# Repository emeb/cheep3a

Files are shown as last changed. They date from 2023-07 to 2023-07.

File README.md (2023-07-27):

# cheep3a
An inexpensive Eurorack audio generator

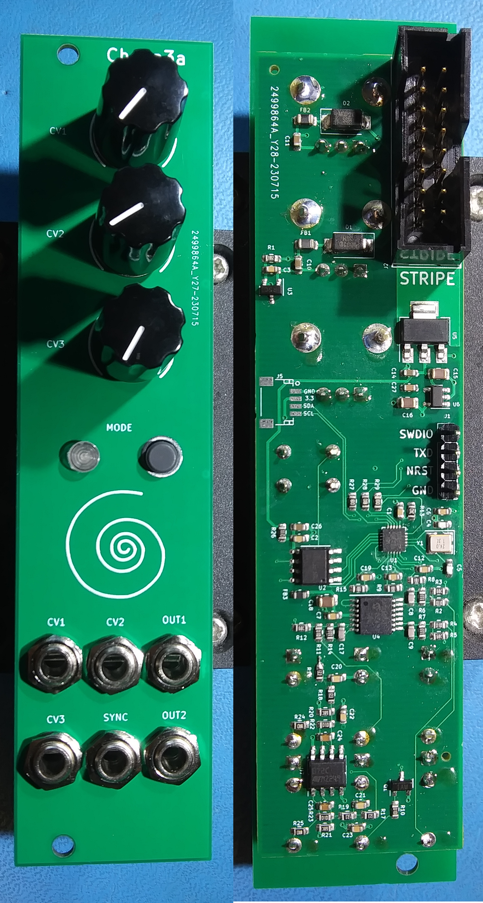
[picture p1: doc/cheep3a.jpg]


## Abstract
This project is an extension of previous "Cheep" Eurorack modules which have been
built as demonstrations for simple, low-cost audio generators using low-end MCUs
and DACs. Cheep3a targets the recently introduced CH32V003 RISC-V based MCU from
WCH Inc. in order to explore the feasibility of audio generation with a sub-$1.00
microcontroller.

## Features
Cheep3a provides the following features:
* Three Control Voltage inputs with 10-bit 10Vpp instantaneous range over a +/-11V
adjustable range using offset potentiometers.
* One digital input for trigger/gate/sync.
* Two +/-5V audio outputs with 16-bit resolution and 48kHz sample rate.
* One mode select button
* One RGB LED for mode indication.
* 4-pin programming interface, including 1-line WCH standard SWDIO, UART TX and
Reset signal.
* JST SH-4 connector with optional I2C signals compatible with StemmaQT/Qwiic
connections for off-board expansion.
* Standard 16-pin Eurorack power with shrouded header and +/-12V supply.

## Firmware
Firmware included in this project supports seven operating modes with various
audio signal outputs in each mode:
1. [Red] Two independent sine oscillators with amplitude control - 10Hz - 10kHz
frequency range.
2. [Green] Same as 1 but with 0.3Hz - 300Hz frequency range.
3. [Yellow] One sine oscillator with two outputs, phase offset and amplitude
control - 10Hz - 10kHz frequency range.
4. [Blue] Pulse wave oscillator with two outputs and independent PWM
controls - 10Hz - 10kHz frequency range.
5. [Magenta] 2-operator FM with index and ratio controls. Mod and Carrier outputs.
6. [Cyan] Two independent clocked noise outputs.
7. [White] White and Pink noise outputs.

Mode selection is stored in the MCU's on-chip flash memory and will persist
across power cycles.

### Building Firmware
The Cheep3a firmware is based on [cnlohr's "ch32v003fun"](https://github.com/cnlohr/ch32v003fun)
project and expects that the github directory for that project is located in
an adjacent directory in order for the make-based build system to operate
correctly. A recent RISC-V GCC toolchain is also required and once you have
that installed (and in your search path) the following steps should work:

```
git clone git@github.com:emeb/cheep3a.git
git clone git@github.com:cnlohr/ch32v003fun.git
cd cheep3a/firmware
make
```

## Hardware
Version 0.1 of the hardware was fabbed and assembled at JLCPCB at modest cost and
all unsupported components (pots, jacks, connectors, LED and button) were added
by hand. Aside from a few minor layout errors which were easily corrected, the
system performed as expected.

### Building Hardware
The hardware can be recreated with the following steps:
1. Open the PCB project in Kicad and generate Gerber and Drill files. Zip them
up together and submit to the PCB fab of choice.
2. Generate component placement information and format as required by your
PCB assembly house.
3. The JLCPCB formatted BOM is included in the hardware directory and maps to
components that were available at the time I designed this board. If you don't
use JLCPCB the BOM may need to be reformatted and substitutions of parts will
likely be necessary.
4. Follow the submission process for your PCB house, including correction of
placement and approval of components.

## Lessons Learned
The CH32V003 MCU performs well for simple audio generation tasks but falls
somewhat short for more complex DSP. Hardware support for good digital audio is
impaired by the overall low CPU clock speed and limited memory capcity, as well
as the need to "work around" the lack of true I2S serial audio interfacing. The
biggest shortcoming however is the subset RV32E RISC-V CPU which doesn't provide
hardware multiply and thus significantly increases the cost of even simple DSP
operations needed for good-quality audio generation.

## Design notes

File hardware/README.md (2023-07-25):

# Hardware
This directory contains the KiCad project files for the Cheep3a hardware design.

# Version
This is Version 0.2

* Version 0.1 of the design was fabbed and assembled by JLCPCB and several minor
issues were discovered. These issues were corrected and the system performed as
designed.
* Version 0.2 corrects the errors found in V0.1 but has not been built or tested.

# Panel Design
The directory `cheep3a_panel` contains a front panel design for standard 3U
Eurorack mounting.

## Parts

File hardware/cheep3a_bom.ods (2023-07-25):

Source: | /home/ericb/Engineering/KBADC/kicad/cheep3a/cheep3a.kicad_sch
Date: | Fri 14 Jul 2023 01:16:01 PM MST
Tool: | Eeschema 6.0.11-3.fc36
Generator: | /usr/share/kicad/plugins/bom_csv_grouped_by_value.py
Component Count: | 84
Individual Components:
Item | Qty | Reference(s) | Value | Footprint | JLC
 |  | C1 | 0.1uf | Capacitor_SMD:C_0603_1608Metric | https://jlcpcb.com/partdetail/Yageo-CC0603KRX7R9BB104/C14663
 |  | C2 | 0.1uf | Capacitor_SMD:C_0603_1608Metric | https://jlcpcb.com/partdetail/Yageo-CC0603KRX7R9BB104/C14663
 |  | C3 | 0.1uf | Capacitor_SMD:C_0603_1608Metric | https://jlcpcb.com/partdetail/Yageo-CC0603KRX7R9BB104/C14663
 |  | C4 | 27pf | Capacitor_SMD:C_0603_1608Metric | https://jlcpcb.com/partdetail/Yageo-CC0603JRNPO9BN270/C107045
 |  | C5 | 27pf | Capacitor_SMD:C_0603_1608Metric | https://jlcpcb.com/partdetail/Yageo-CC0603JRNPO9BN270/C107045
 |  | C6 | 0.1uf | Capacitor_SMD:C_0603_1608Metric | https://jlcpcb.com/partdetail/Yageo-CC0603KRX7R9BB104/C14663
 |  | C7 | 0.1uf | Capacitor_SMD:C_0603_1608Metric | https://jlcpcb.com/partdetail/Yageo-CC0603KRX7R9BB104/C14663
 |  | C8 | 330pf | Capacitor_SMD:C_0603_1608Metric | https://jlcpcb.com/partdetail/2016-CL10C331JB8NNNC/C1664
 |  | C9 | 330pf | Capacitor_SMD:C_0603_1608Metric | https://jlcpcb.com/partdetail/2016-CL10C331JB8NNNC/C1664
 |  | C10 | 1uf | Capacitor_SMD:C_0603_1608Metric | https://jlcpcb.com/partdetail/16531-CL10A105KB8NNNC/C15849
 |  | C11 | 1uf | Capacitor_SMD:C_0603_1608Metric | https://jlcpcb.com/partdetail/16531-CL10A105KB8NNNC/C15849
 |  | C12 | 0.1uf | Capacitor_SMD:C_0603_1608Metric | https://jlcpcb.com/partdetail/Yageo-CC0603KRX7R9BB104/C14663
 |  | C13 | 0.1uf | Capacitor_SMD:C_0603_1608Metric | https://jlcpcb.com/partdetail/Yageo-CC0603KRX7R9BB104/C14663
 |  | C14 | 1uf | Capacitor_SMD:C_0603_1608Metric | https://jlcpcb.com/partdetail/16531-CL10A105KB8NNNC/C15849
 |  | C15 | 10uf | Capacitor_SMD:C_0805_2012Metric | https://jlcpcb.com/partdetail/439567-GRM21BR61H106KE43L/C440198
 |  | C16 | 10uf | Capacitor_SMD:C_0805_2012Metric | https://jlcpcb.com/partdetail/439567-GRM21BR61H106KE43L/C440198
 |  | C17 | 330pf | Capacitor_SMD:C_0603_1608Metric | https://jlcpcb.com/partdetail/2016-CL10C331JB8NNNC/C1664
 |  | C18 | 10uf | Capacitor_SMD:C_0805_2012Metric | https://jlcpcb.com/partdetail/439567-GRM21BR61H106KE43L/C440198
 |  | C19 | 0.1uf | Capacitor_SMD:C_0603_1608Metric | https://jlcpcb.com/partdetail/Yageo-CC0603KRX7R9BB104/C14663
 |  | C20 | 3.3nf | Capacitor_SMD:C_0603_1608Metric | https://jlcpcb.com/partdetail/1965-CL10B332KB8NNNC/C1613
 |  | C21 | 3.3nf | Capacitor_SMD:C_0603_1608Metric | https://jlcpcb.com/partdetail/1965-CL10B332KB8NNNC/C1613
 |  | C22 | 0.1uf | Capacitor_SMD:C_0603_1608Metric | https://jlcpcb.com/partdetail/Yageo-CC0603KRX7R9BB104/C14663
 |  | C23 | 0.1uf | Capacitor_SMD:C_0603_1608Metric | https://jlcpcb.com/partdetail/Yageo-CC0603KRX7R9BB104/C14663
 |  | C24 | 150pf | Capacitor_SMD:C_0603_1608Metric | https://jlcpcb.com/partdetail/1946-0603B151K500NT/C1594
 |  | C25 | 150pf | Capacitor_SMD:C_0603_1608Metric | https://jlcpcb.com/partdetail/1946-0603B151K500NT/C1594
 |  | C26 | 1uf | Capacitor_SMD:C_0603_1608Metric | https://jlcpcb.com/partdetail/16531-CL10A105KB8NNNC/C15849
 |  | C27 | 10nf | Capacitor_SMD:C_0603_1608Metric | https://jlcpcb.com/partdetail/58143-0603B103K500NT/C57112
 |  | D1 | SS14 | Diode_SMD:D_SMA | https://jlcpcb.com/partdetail/Mdd-SS14/C2480
 |  | D2 | SS14 | Diode_SMD:D_SMA | https://jlcpcb.com/partdetail/Mdd-SS14/C2480
 |  | D3 | CLX6F-FKC | LED_SMD:LED_RGB_PLCC-6
 |  | FB1 | GZ2012D601TF | Inductor_SMD:L_0805_2012Metric | https://jlcpcb.com/partdetail/Sunlord-GZ2012D601TF/C1017
 |  | FB2 | GZ2012D601TF | Inductor_SMD:L_0805_2012Metric | https://jlcpcb.com/partdetail/Sunlord-GZ2012D601TF/C1017
 |  | FB3 | GZ1608D222TF | Inductor_SMD:L_0603_1608Metric | https://jlcpcb.com/partdetail/Sunlord-GZ1608D222TF/C96697
 |  | J1 | PROGRAM | Connector_PinHeader_2.54mm:PinHeader_1x04_P2.54mm_Vertical
 |  | J2 | Conn_02x08_Odd_Even | emeb_library:con16_2X8_S4_TEC
 |  | J3 | AudioJack2_SwitchT | emeb_library:Jack_3.5mm_QingPu_WQP-PJ398SM_Vertical_CircularHoles
 |  | J4 | AudioJack2_SwitchT | emeb_library:Jack_3.5mm_QingPu_WQP-PJ398SM_Vertical_CircularHoles
 |  | J5 | JST SH-4 (Qwiic) | emeb_library:JST_SH_SM04B-SRSS-TB_04x1.00mm_Angled
 |  | J6 | AudioJack2_SwitchT | emeb_library:Jack_3.5mm_QingPu_WQP-PJ398SM_Vertical_CircularHoles
 |  | J7 | AudioJack2_SwitchT | emeb_library:Jack_3.5mm_QingPu_WQP-PJ398SM_Vertical_CircularHoles
 |  | J8 | AudioJack2_SwitchT | emeb_library:Jack_3.5mm_QingPu_WQP-PJ398SM_Vertical_CircularHoles
 |  | J9 | AudioJack2_SwitchT | emeb_library:Jack_3.5mm_QingPu_WQP-PJ398SM_Vertical_CircularHoles
 |  | Q1 | MMBT3904 | Package_TO_SOT_SMD:SOT-23 | https://jlcpcb.com/partdetail/Goodwork-MMBT3904/C909754
 |  | R1 | 1.5k | Resistor_SMD:R_0603_1608Metric | https://jlcpcb.com/partdetail/21904-0603WAF1001T5E/C21190
 |  | R2 | 100k | Resistor_SMD:R_0603_1608Metric | https://jlcpcb.com/partdetail/26546-0603WAF1003T5E/C25803
 |  | R3 | 49.9k | Resistor_SMD:R_0603_1608Metric | https://jlcpcb.com/partdetail/23911-0603WAF4992T5E/C23184
 |  | R4 | 100k | Resistor_SMD:R_0603_1608Metric | https://jlcpcb.com/partdetail/26546-0603WAF1003T5E/C25803
 |  | R5 | 49.9k | Resistor_SMD:R_0603_1608Metric | https://jlcpcb.com/partdetail/23911-0603WAF4992T5E/C23184
 |  | R6 | 33k | Resistor_SMD:R_0603_1608Metric | https://jlcpcb.com/partdetail/4623-0603WAF3302T5E/C4216
 |  | R7 | 33k | Resistor_SMD:R_0603_1608Metric | https://jlcpcb.com/partdetail/4623-0603WAF3302T5E/C4216
 |  | R8 | 180 | Resistor_SMD:R_0603_1608Metric | https://jlcpcb.com/partdetail/23555-0603WAF1800T5E/C22828
 |  | R9 | 180 | Resistor_SMD:R_0603_1608Metric | https://jlcpcb.com/partdetail/23555-0603WAF1800T5E/C22828
 |  | R10 | 100k | Resistor_SMD:R_0603_1608Metric | https://jlcpcb.com/partdetail/26546-0603WAF1003T5E/C25803
 |  | R11 | 100k | Resistor_SMD:R_0603_1608Metric | https://jlcpcb.com/partdetail/26546-0603WAF1003T5E/C25803
 |  | R12 | 49.9k | Resistor_SMD:R_0603_1608Metric | https://jlcpcb.com/partdetail/23911-0603WAF4992T5E/C23184
 |  | R13 | 10k | Resistor_SMD:R_0603_1608Metric | https://jlcpcb.com/partdetail/26547-0603WAF1002T5E/C25804
 |  | R14 | 33k | Resistor_SMD:R_0603_1608Metric | https://jlcpcb.com/partdetail/4623-0603WAF3302T5E/C4216
 |  | R15 | 180 | Resistor_SMD:R_0603_1608Metric | https://jlcpcb.com/partdetail/23555-0603WAF1800T5E/C22828
 |  | R16 | 12k | Resistor_SMD:R_0603_1608Metric | https://jlcpcb.com/partdetail/23517-0603WAF1202T5E/C22790
 |  | R17 | 12k | Resistor_SMD:R_0603_1608Metric | https://jlcpcb.com/partdetail/23517-0603WAF1202T5E/C22790
 |  | R18 | 12k | Resistor_SMD:R_0603_1608Metric | https://jlcpcb.com/partdetail/23517-0603WAF1202T5E/C22790
 |  | R19 | 12k | Resistor_SMD:R_0603_1608Metric | https://jlcpcb.com/partdetail/23517-0603WAF1202T5E/C22790
 |  | R20 | 49.9k | Resistor_SMD:R_0603_1608Metric | https://jlcpcb.com/partdetail/23911-0603WAF4992T5E/C23184
 |  | R21 | 49.9k | Resistor_SMD:R_0603_1608Metric | https://jlcpcb.com/partdetail/23911-0603WAF4992T5E/C23184
 |  | R22 | 100k | Resistor_SMD:R_0603_1608Metric | https://jlcpcb.com/partdetail/26546-0603WAF1003T5E/C25803
 |  | R23 | 100k | Resistor_SMD:R_0603_1608Metric | https://jlcpcb.com/partdetail/26546-0603WAF1003T5E/C25803
 |  | R24 | 100 | Resistor_SMD:R_0603_1608Metric | https://jlcpcb.com/partdetail/23502-0603WAF1000T5E/C22775
 |  | R25 | 100 | Resistor_SMD:R_0603_1608Metric | https://jlcpcb.com/partdetail/23502-0603WAF1000T5E/C22775
 |  | R26 | 10 | Resistor_SMD:R_0603_1608Metric | https://jlcpcb.com/partdetail/23586-0603WAF100JT5E/C22859
 |  | R27 | 1k | Resistor_SMD:R_0603_1608Metric | https://jlcpcb.com/partdetail/21904-0603WAF1001T5E/C21190
 |  | R28 | 1k | Resistor_SMD:R_0603_1608Metric | https://jlcpcb.com/partdetail/21904-0603WAF1001T5E/C21190
 |  | R29 | 1k | Resistor_SMD:R_0603_1608Metric | https://jlcpcb.com/partdetail/21904-0603WAF1001T5E/C21190
 |  | RV1 | 10k | emeb_library:Potentiometer_TT_P0915N
 |  | RV2 | 10k | emeb_library:Potentiometer_TT_P0915N
 |  | RV3 | 10k | emeb_library:Potentiometer_TT_P0915N
 |  | SW1 | SW_Push | Button_Switch_THT:SW_PUSH_6mm
 |  | U1 | CH32V003F4U6 | Package_DFN_QFN:QFN-20-1EP_3x3mm_P0.4mm_EP1.65x1.65mm_ThermalVias | https://jlcpcb.com/partdetail/wch_jiangsu_Qin_heng-CH32V003F4U6/C5299908
 |  | U2 | PT8211-S | Package_SO:SO-8_3.9x4.9mm_P1.27mm | https://jlcpcb.com/partdetail/ptc_princeton_tech-PT8211S/C92004
 |  | U3 | LM4040C50FTA | Package_TO_SOT_SMD:SOT-23 | https://jlcpcb.com/partdetail/DiodesIncorporated-LM4040C50FTA/C156291
 |  | U4 | MCP6004-I/ST | Package_SO:TSSOP-14_4.4x5mm_P0.65mm | https://jlcpcb.com/partdetail/MicrochipTech-MCP6004T_IST/C50282
 |  | U5 | ME6118A50B3G | Package_TO_SOT_SMD:SOT-223-3_TabPin2 | https://jlcpcb.com/partdetail/162404-ME6118A50B3G/C151064
 |  | U6 | BCT2028EUK33 | Package_TO_SOT_SMD:SOT-23-5 | https://jlcpcb.com/partdetail/Broadchip-BCT2028EUK33TR/C266766
 |  | U7 | TL072CDT | Package_SO:SOIC-8_3.9x4.9mm_P1.27mm | https://jlcpcb.com/partdetail/Stmicroelectronics-TL072CDT/C6961
 |  | Y1 | SX32Y024000BK1T | Crystal:Crystal_SMD_3225-4Pin_3.2x2.5mm | https://jlcpcb.com/partdetail/Tkd-SX32Y024000BK1T/C271630
Collated Components:
Item | Qty | Reference(s) | Value | Footprint | JLC | checked?
1 | 10 | C1, C2, C3, C6, C7, C12, C13, C19, C22, C23 | 0.1uf | Capacitor_SMD:C_0603_1608Metric | https://jlcpcb.com/partdetail/Yageo-CC0603KRX7R9BB104/C14663 | Yes
2 | 2 | C4, C5 | 27pf | Capacitor_SMD:C_0603_1608Metric | https://jlcpcb.com/partdetail/Yageo-CC0603JRNPO9BN270/C107045 | Yes
3 | 3 | C8, C9, C17 | 330pf | Capacitor_SMD:C_0603_1608Metric | https://jlcpcb.com/partdetail/2016-CL10C331JB8NNNC/C1664 | Yes
4 | 4 | C10, C11, C14, C26 | 1uf | Capacitor_SMD:C_0603_1608Metric | https://jlcpcb.com/partdetail/16531-CL10A105KB8NNNC/C15849 | Yes
5 | 3 | C15, C16, C18 | 10uf | Capacitor_SMD:C_0805_2012Metric | https://jlcpcb.com/partdetail/439567-GRM21BR61H106KE43L/C440198 | Yes
6 | 2 | C20, C21 | 3.3nf | Capacitor_SMD:C_0603_1608Metric | https://jlcpcb.com/partdetail/1965-CL10B332KB8NNNC/C1613 | Yes
7 | 2 | C24, C25 | 150pf | Capacitor_SMD:C_0603_1608Metric | https://jlcpcb.com/partdetail/1946-0603B151K500NT/C1594 | Yes
8 | 1 | C27 | 10nf | Capacitor_SMD:C_0603_1608Metric | https://jlcpcb.com/partdetail/58143-0603B103K500NT/C57112 | Yes
9 | 2 | D1, D2 | SS14 | Diode_SMD:D_SMA | https://jlcpcb.com/partdetail/Mdd-SS14/C2480 | Yes
10 | 1 | D3 | CLX6F-FKC | LED_SMD:LED_RGB_PLCC-6
11 | 2 | FB1, FB2 | GZ2012D601TF | Inductor_SMD:L_0805_2012Metric | https://jlcpcb.com/partdetail/Sunlord-GZ2012D601TF/C1017 | Yes
12 | 1 | FB3 | GZ1608D222TF | Inductor_SMD:L_0603_1608Metric | https://jlcpcb.com/partdetail/Sunlord-GZ1608D222TF/C96697 | Yes
13 | 1 | J1 | PROGRAM | Connector_PinHeader_2.54mm:PinHeader_1x04_P2.54mm_Vertical
14 | 1 | J2 | Conn_02x08_Odd_Even | emeb_library:con16_2X8_S4_TEC
15 | 6 | J3, J4, J6, J7, J8, J9 | AudioJack2_SwitchT | emeb_library:Jack_3.5mm_QingPu_WQP-PJ398SM_Vertical_CircularHoles
16 | 1 | J5 | JST SH-4 (Qwiic) | emeb_library:JST_SH_SM04B-SRSS-TB_04x1.00mm_Angled
17 | 1 | Q1 | MMBT3904 | Package_TO_SOT_SMD:SOT-23 | https://jlcpcb.com/partdetail/Goodwork-MMBT3904/C909754 | Yes
18 | 1 | R1 | 1.8k | Resistor_SMD:R_0603_1608Metric | https://jlcpcb.com/partdetail/4584-0603WAF1801T5E/C4177 | Yes
19 | 6 | R2, R4, R10, R11, R22, R23 | 100k | Resistor_SMD:R_0603_1608Metric | https://jlcpcb.com/partdetail/26546-0603WAF1003T5E/C25803 | Yes
20 | 5 | R3, R5, R12, R20, R21 | 49.9k | Resistor_SMD:R_0603_1608Metric | https://jlcpcb.com/partdetail/23911-0603WAF4992T5E/C23184 | Yes
21 | 3 | R6, R7, R14 | 33k | Resistor_SMD:R_0603_1608Metric | https://jlcpcb.com/partdetail/4623-0603WAF3302T5E/C4216 | Yes
22 | 3 | R8, R9, R15 | 180 | Resistor_SMD:R_0603_1608Metric | https://jlcpcb.com/partdetail/23555-0603WAF1800T5E/C22828 | Yes
23 | 1 | R13 | 10k | Resistor_SMD:R_0603_1608Metric | https://jlcpcb.com/partdetail/26547-0603WAF1002T5E/C25804 | Yes
24 | 4 | R16, R17, R18, R19 | 12k | Resistor_SMD:R_0603_1608Metric | https://jlcpcb.com/partdetail/23517-0603WAF1202T5E/C22790 | Yes
25 | 2 | R24, R25 | 100 | Resistor_SMD:R_0603_1608Metric | https://jlcpcb.com/partdetail/23502-0603WAF1000T5E/C22775 | Yes
26 | 1 | R26 | 10 | Resistor_SMD:R_0603_1608Metric | https://jlcpcb.com/partdetail/23586-0603WAF100JT5E/C22859 | Yes
27 | 3 | R27, R28, R29 | 1k | Resistor_SMD:R_0603_1608Metric | https://jlcpcb.com/partdetail/21904-0603WAF1001T5E/C21190 | Yes
28 | 3 | RV1, RV2, RV3 | 10k | emeb_library:Potentiometer_TT_P0915N
29 | 1 | SW1 | SW_Push | Button_Switch_THT:SW_PUSH_6mm
30 | 1 | U1 | CH32V003F4U6 | Package_DFN_QFN:QFN-20-1EP_3x3mm_P0.4mm_EP1.65x1.65mm_ThermalVias | https://jlcpcb.com/partdetail/wch_jiangsu_Qin_heng-CH32V003F4U6/C5299908 | Yes
31 | 1 | U2 | PT8211-S | Package_SO:SO-8_3.9x4.9mm_P1.27mm | https://jlcpcb.com/partdetail/ptc_princeton_tech-PT8211S/C92004 | Yes
32 | 1 | U3 | LM4040C50FTA | Package_TO_SOT_SMD:SOT-23 | https://jlcpcb.com/partdetail/DiodesIncorporated-LM4040C50FTA/C156291 | Yes
33 | 1 | U4 | MCP6004-I/ST | Package_SO:TSSOP-14_4.4x5mm_P0.65mm | https://jlcpcb.com/partdetail/MicrochipTech-MCP6004T_IST/C50282 | Yes
34 | 1 | U5 | ME6118A50B3G | Package_TO_SOT_SMD:SOT-223-3_TabPin2 | https://jlcpcb.com/partdetail/162404-ME6118A50B3G/C151064 | Yes
35 | 1 | U6 | BCT2028EUK33 | Package_TO_SOT_SMD:SOT-23-5 | https://jlcpcb.com/partdetail/Broadchip-BCT2028EUK33TR/C266766 | Yes
36 | 1 | U7 | TL072CDT | Package_SO:SOIC-8_3.9x4.9mm_P1.27mm | https://jlcpcb.com/partdetail/Stmicroelectronics-TL072CDT/C6961 | Yes
37 | 1 | Y1 | SX32Y024000BK1T | Crystal:Crystal_SMD_3225-4Pin_3.2x2.5mm | https://jlcpcb.com/partdetail/Tkd-SX32Y024000BK1T/C271630 | Yes

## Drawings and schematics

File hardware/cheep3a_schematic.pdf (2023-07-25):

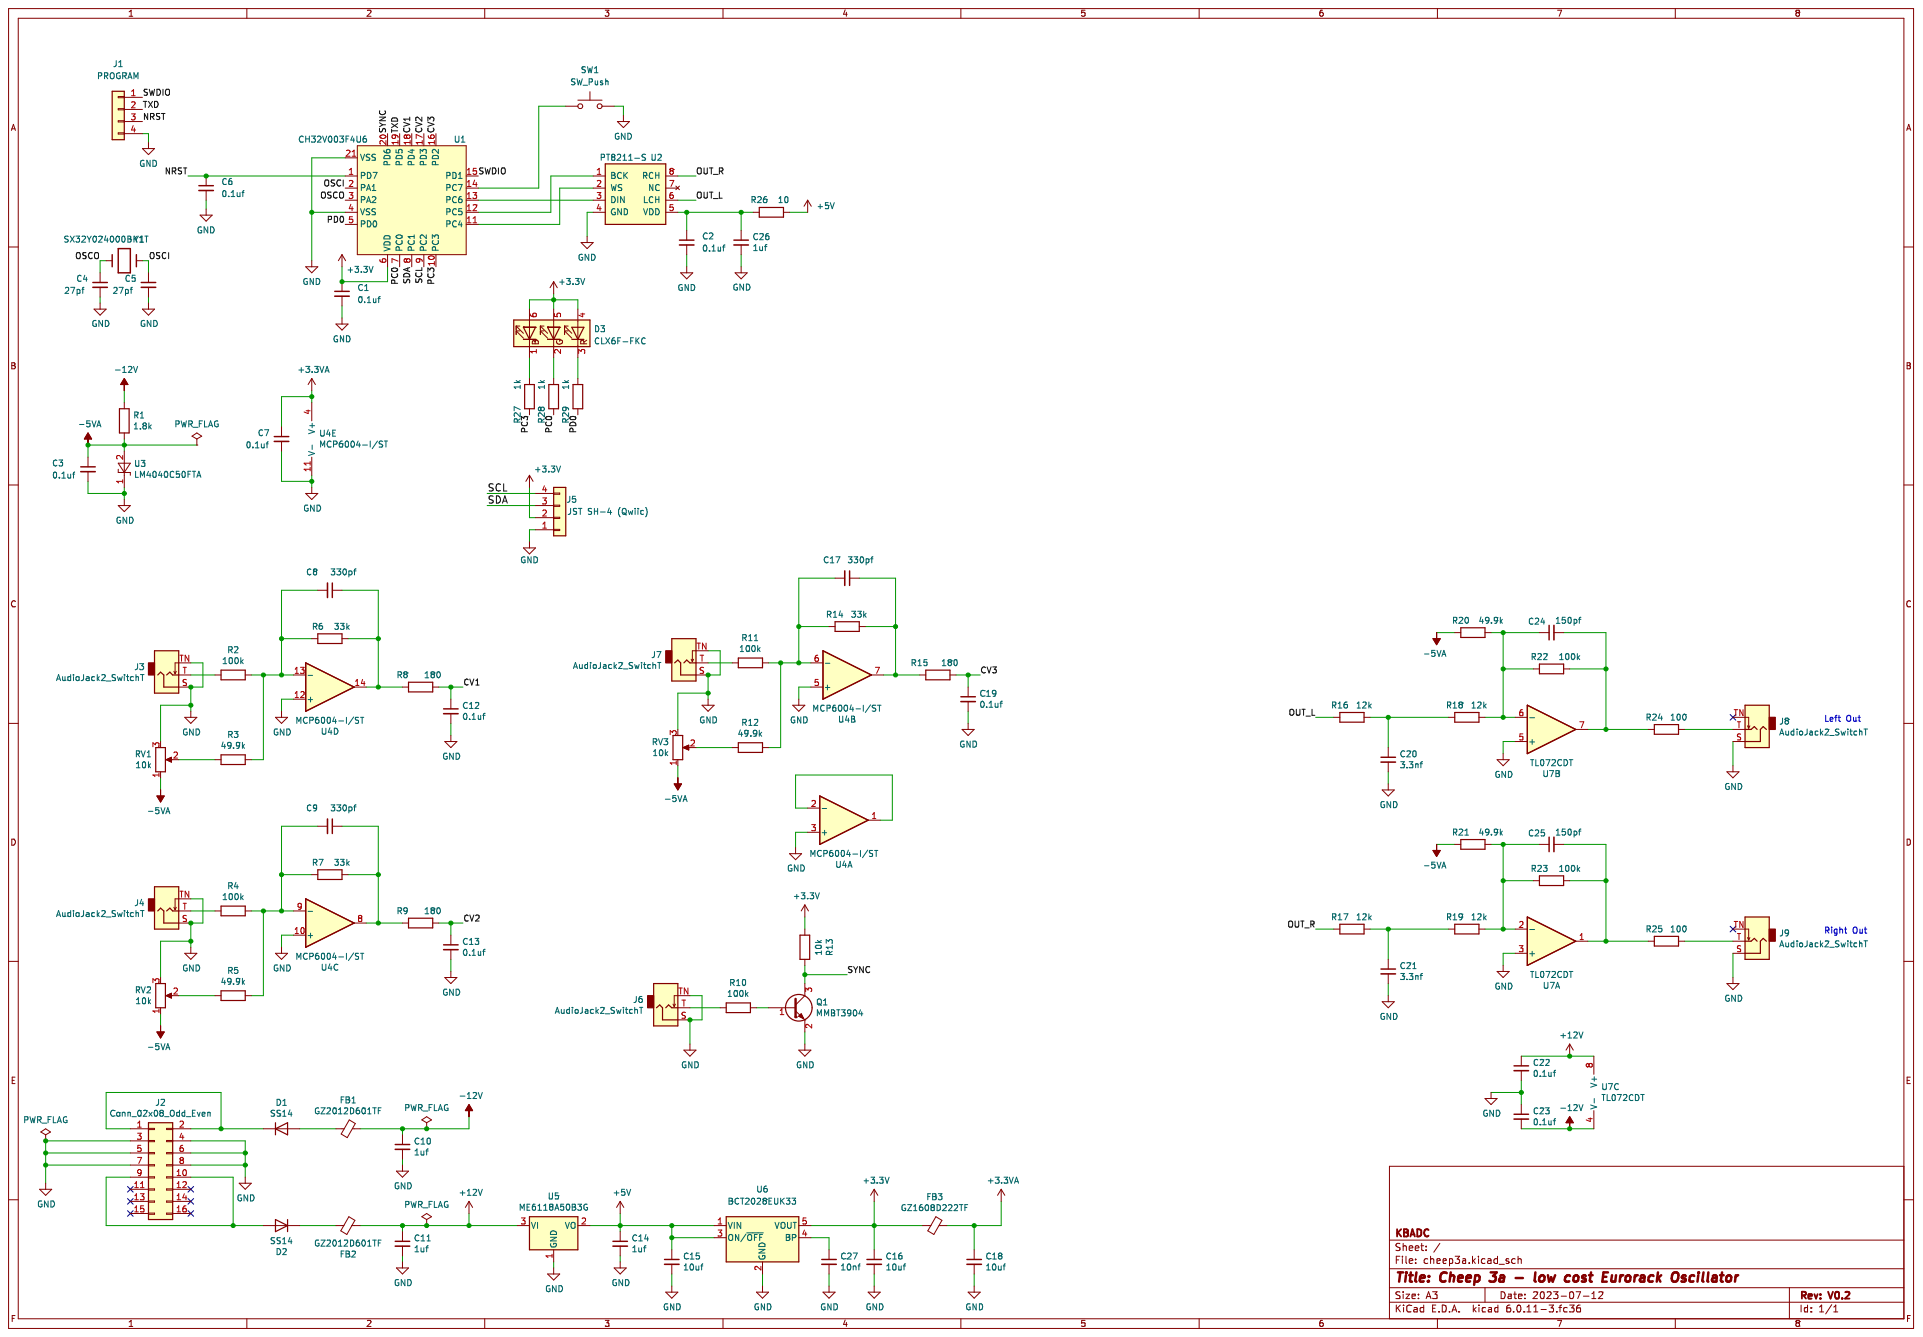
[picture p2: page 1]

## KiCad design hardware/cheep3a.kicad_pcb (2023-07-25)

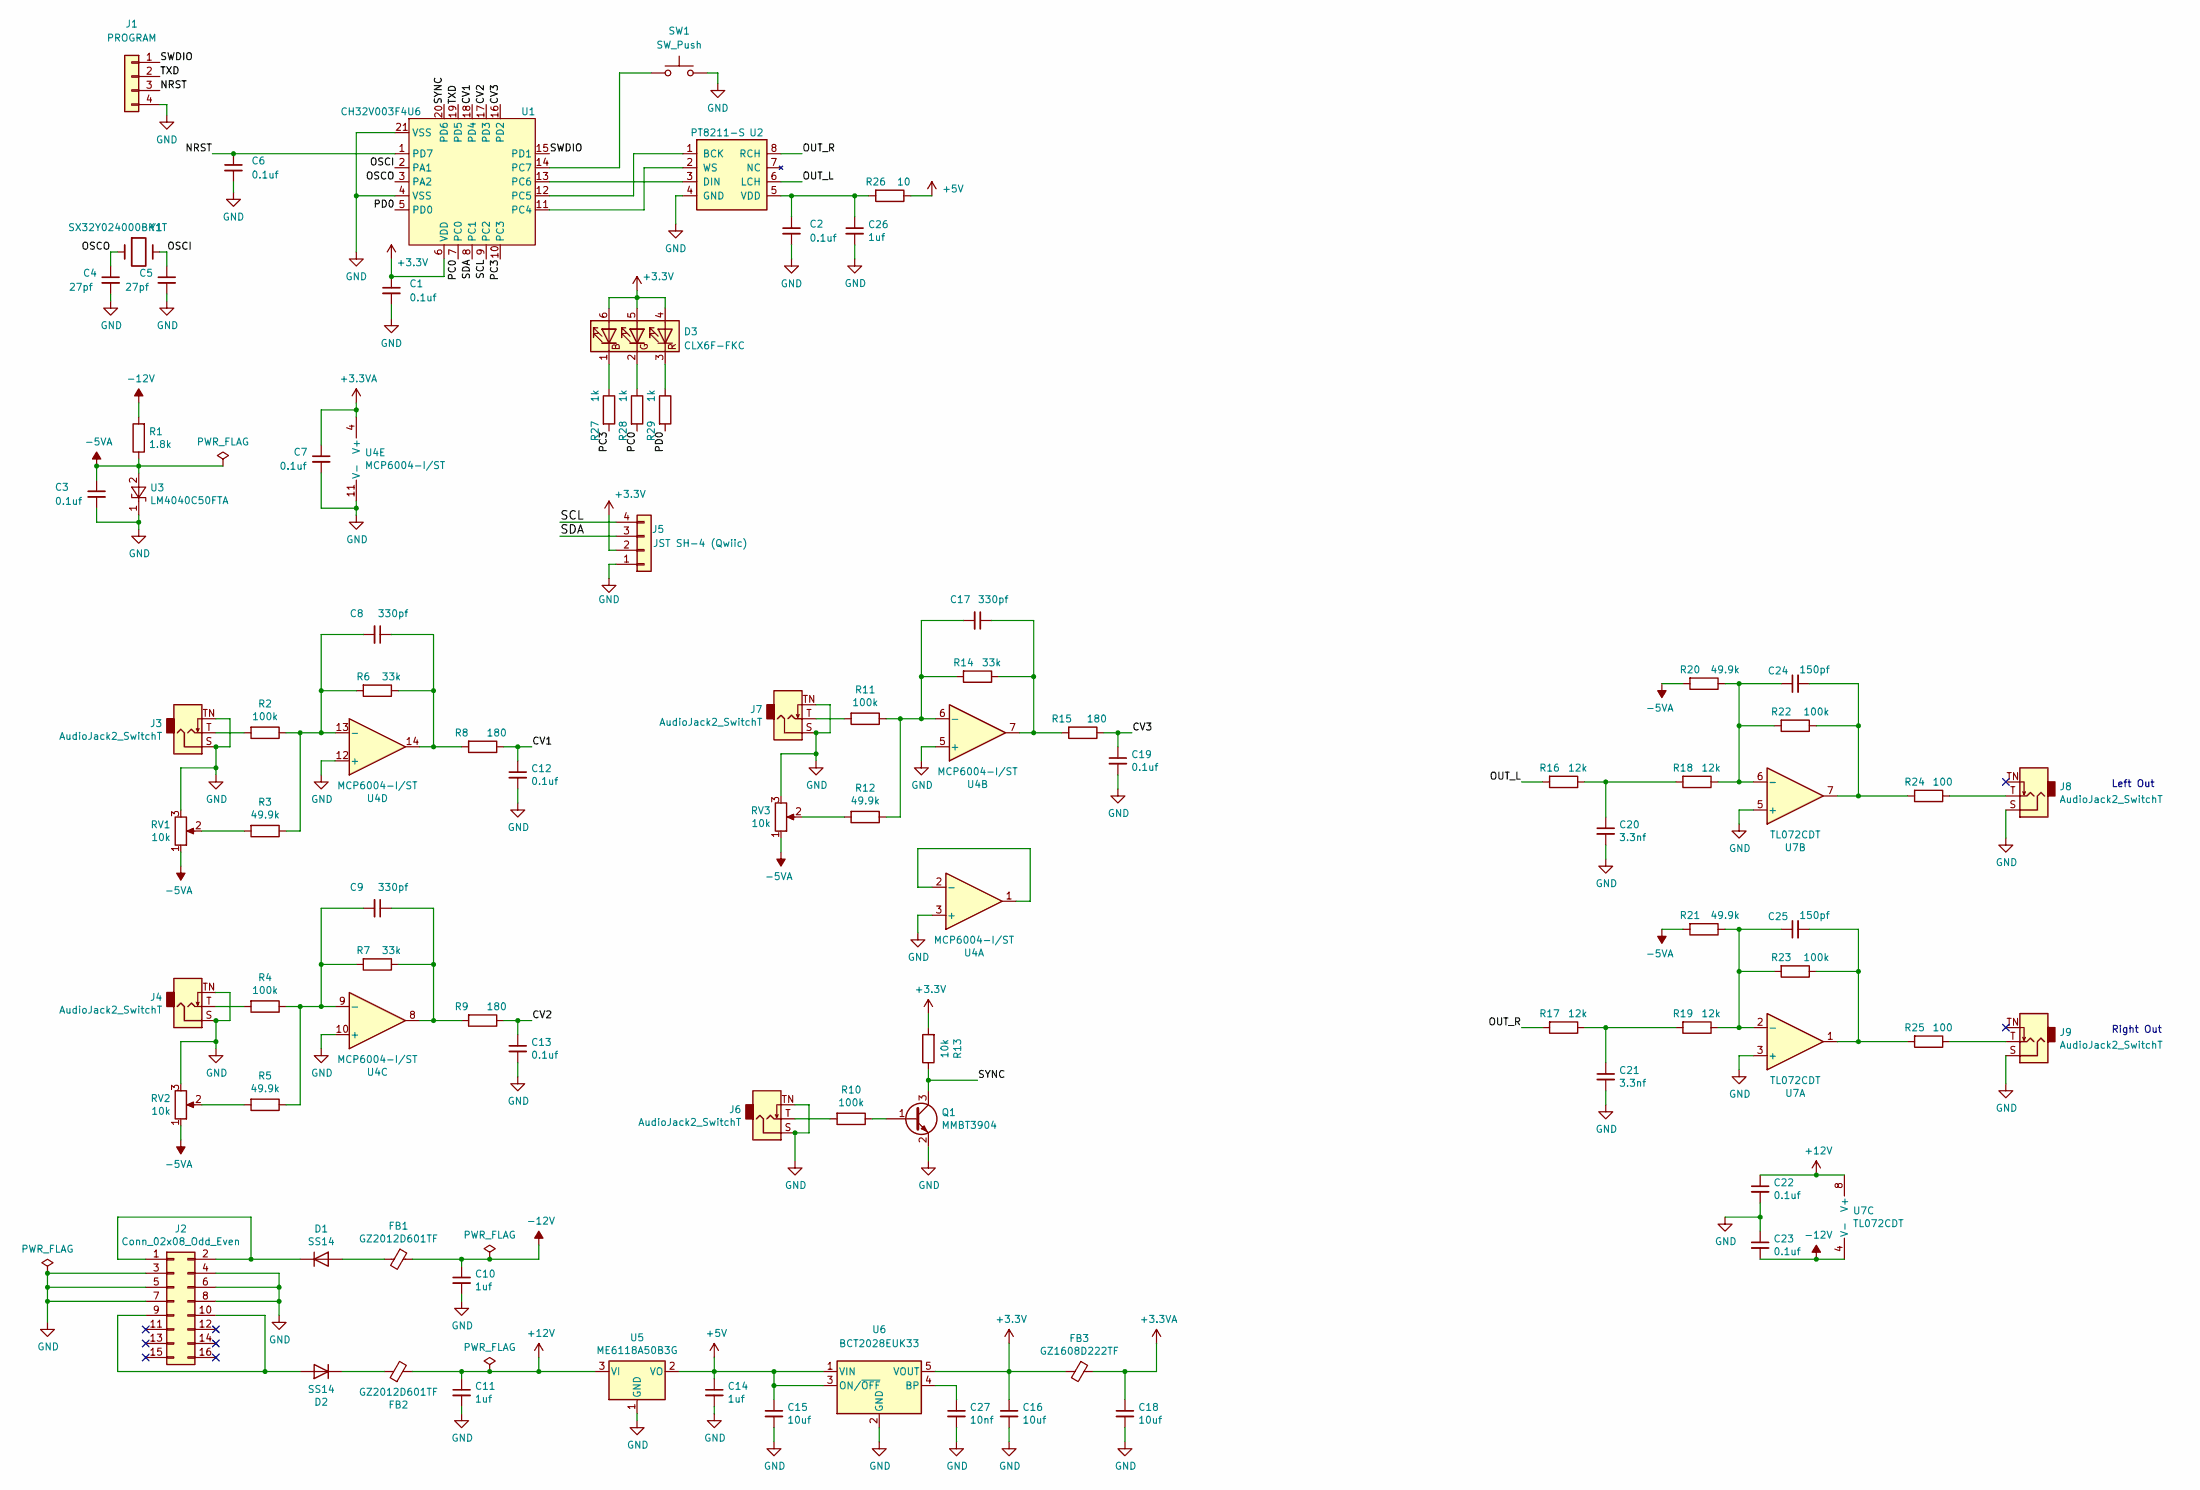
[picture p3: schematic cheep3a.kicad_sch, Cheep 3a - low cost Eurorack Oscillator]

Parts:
C1, C2, C3, C6, C7, C12, C13, C19, C22, C23: 0.1uf; C_0603_1608Metric
C4, C5: 27pf; C_0603_1608Metric
C8, C9, C17: 330pf; C_0603_1608Metric
C10, C11, C14, C26: 1uf; C_0603_1608Metric
C15, C16, C18: 10uf; C_0805_2012Metric
C20, C21: 3.3nf; C_0603_1608Metric
C24, C25: 150pf; C_0603_1608Metric
C27: 10nf; C_0603_1608Metric
D1, D2: SS14; D_SMA
D3: CLX6F-FKC; LED_RGB_PLCC-6
FB1, FB2: GZ2012D601TF; L_0805_2012Metric
FB3: GZ1608D222TF; L_0603_1608Metric
J1: PROGRAM; PinHeader_1x04_P2.54mm_Vertical
J2: Conn_02x08_Odd_Even; con16_2X8_S4_TEC
J3, J4, J6, J7, J8, J9: AudioJack2_SwitchT; Jack_3.5mm_QingPu_WQP-PJ398SM_Vertical_CircularHoles
J5: JST SH-4 (Qwiic); JST_SH_SM04B-SRSS-TB_04x1.00mm_Angled
Q1: MMBT3904; SOT-23
R1: 1.8k; R_0603_1608Metric
R2, R4, R10, R11, R22, R23: 100k; R_0603_1608Metric
R3, R5, R12, R20, R21: 49.9k; R_0603_1608Metric
R6, R7, R14: 33k; R_0603_1608Metric
R8, R9, R15: 180; R_0603_1608Metric
R13: 10k; R_0603_1608Metric
R16, R17, R18, R19: 12k; R_0603_1608Metric
R24, R25: 100; R_0603_1608Metric
R26: 10; R_0603_1608Metric
R27, R28, R29: 1k; R_0603_1608Metric
RV1, RV2, RV3: 10k; Potentiometer_TT_P0915N
SW1: SW_Push; SW_PUSH_6mm
U1: CH32V003F4U6; QFN-20-1EP_3x3mm_P0.4mm_EP1.65x1.65mm_ThermalVias
U2: PT8211-S; SO-8_3.9x4.9mm_P1.27mm
U3: LM4040C50FTA; SOT-23
U4: MCP6004-I/ST; TSSOP-14_4.4x5mm_P0.65mm
U5: ME6118A50B3G; SOT-223-3_TabPin2
U6: BCT2028EUK33; SOT-23-5
U7: TL072CDT; SOIC-8_3.9x4.9mm_P1.27mm
Y1: SX32Y024000BK1T; Crystal_SMD_3225-4Pin_3.2x2.5mm

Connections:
+3.3V: C1.1, C16.1, D3.4 (BA), D3.5 (GA), D3.6 (RA), FB3.2, J5.2, R13.2, U1.6 (VDD), U6.5 (VOUT)
+3.3VA: C7.1, C18.1, FB3.1, U4.4 (V+)
+5V: C14.1, C15.1, R26.1, U5.2 (VO), U6.1 (VIN), U6.3 (ON/~OFF)
+12V: C11.1, C22.1, FB2.2, U5.3 (VI), U7.8 (V+)
-5VA: C3.1, R1.1, R20.2, R21.2, RV1.1, RV2.1, RV3.1, U3.2 (A)
-12V: C10.1, C23.2, FB1.1, R1.2, U7.4 (V-)
/CV1: C12.1, R8.1, U1.18 (PD4)
/CV2: C13.1, R9.1, U1.17 (PD3)
/CV3: C19.1, R15.1, U1.16 (PD2)
/NRST: C6.1, J1.3, U1.1 (PD7)
/OSCI: C5.1, U1.2 (PA1), Y1.3
/OSCO: C4.1, U1.3 (PA2), Y1.1
/OUT_L: R16.2, U2.6 (LCH)
/OUT_R: R17.2, U2.8 (RCH)
/PC0: R28.2, U1.7 (PC0)
/PC3: R27.2, U1.10 (PC3)
/PD0: R29.2, U1.5 (PD0)
/SCL: J5.4, U1.9 (PC2)
/SDA: J5.3, U1.8 (PC1)
/SWDIO: J1.1, U1.15 (PD1)
/SYNC: Q1.3 (C), R13.1, U1.20 (PD6)
/TXD: J1.2, U1.19 (PD5)
GND: C1.2, C2.2, C3.2, C4.2, C5.2, C6.2, C7.2, C10.2, C11.2, C12.2, C13.2, C14.2, C15.2, C16.2, C18.2, C19.2, C20.2, C21.2, C22.2, C23.1, C26.2, C27.2, J1.4, J2.3, J2.4, J2.5, J2.6, J2.7, J2.8, J3.S, J3.TN, J4.S, J4.TN, J5.1, J6.S, J6.TN, J7.S, J7.TN, J8.S, J9.S, Q1.2 (E), RV1.3, RV2.3, RV3.3, SW1.2, U1.4 (VSS), U1.21 (VSS), U2.4 (GND), U3.1 (K), U4.3 (+), U4.5 (+), U4.10 (+), U4.11 (V-), U4.12 (+), U5.1 (GND), U6.2 (GND), U7.3 (+), U7.5 (+)
unnamed: C2.1, C26.1, R26.2, U2.5 (VDD)
unnamed: C8.1, R6.1, R8.2, U4.14
unnamed: C8.2, R2.1, R3.1, R6.2, U4.13 (-)
unnamed: C9.1, R7.1, R9.2, U4.8
unnamed: C9.2, R4.1, R5.1, R7.2, U4.9 (-)
unnamed: C17.1, R14.1, R15.2, U4.7
unnamed: C17.2, R11.1, R12.1, R14.2, U4.6 (-)
unnamed: C20.1, R16.1, R18.2
unnamed: C21.1, R17.1, R19.2
unnamed: C24.1, R18.1, R20.1, R22.2, U7.6 (-)
unnamed: C24.2, R22.1, R24.2, U7.7
unnamed: C25.1, R19.1, R21.1, R23.2, U7.2 (-)
unnamed: C25.2, R23.1, R25.2, U7.1
unnamed: C27.1, U6.4 (BP)
unnamed: D1.1 (K), J2.1, J2.2
unnamed: D1.2 (A), FB1.2
unnamed: D2.1 (K), FB2.1
unnamed: D2.2 (A), J2.9, J2.10
unnamed: D3.1 (RK), R27.1
unnamed: D3.2 (GK), R28.1
unnamed: D3.3 (BK), R29.1
unnamed: J3.T, R2.2
unnamed: J4.T, R4.2
unnamed: J6.T, R10.2
unnamed: J7.T, R11.2
unnamed: J8.T, R24.1
unnamed: J9.T, R25.1
unnamed: Q1.1 (B), R10.1
unnamed: R3.2, RV1.2
unnamed: R5.2, RV2.2
unnamed: R12.2, RV3.2
unnamed: SW1.1, U1.14 (PC7)
unnamed: U1.11 (PC4), U2.2 (WS)
unnamed: U1.12 (PC5), U2.1 (BCK)
unnamed: U1.13 (PC6), U2.3 (DIN)
unnamed: U4.1, U4.2 (-)

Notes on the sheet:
Right Out
Left Out

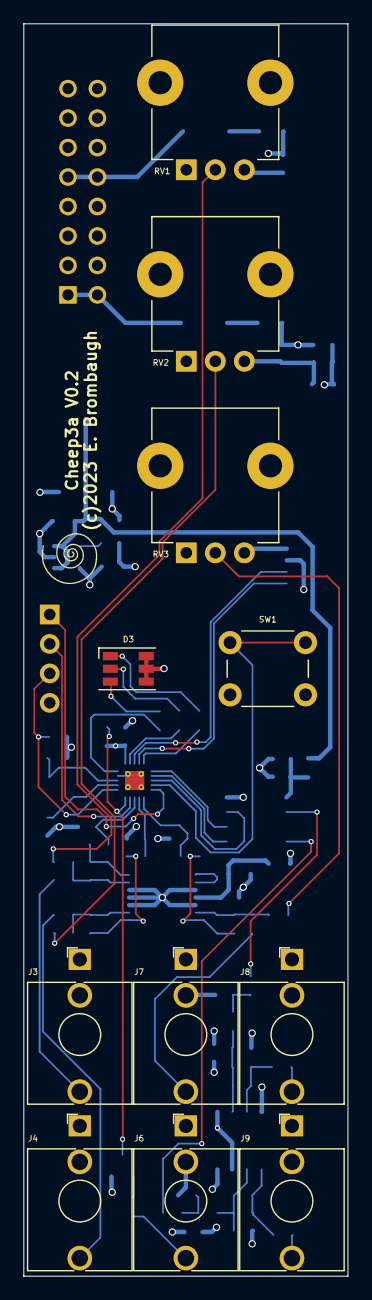
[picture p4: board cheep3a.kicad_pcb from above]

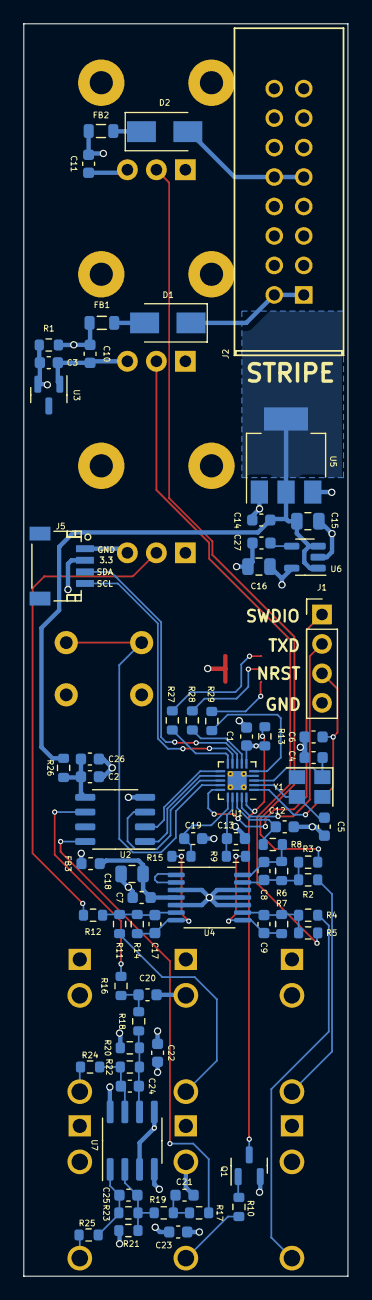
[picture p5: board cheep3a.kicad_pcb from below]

Board: 4 copper layers, 27.9 x 108.0 mm, 85 parts (73 on the bottom side), 59 nets.

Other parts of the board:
Ref**: Val**; avatar_small

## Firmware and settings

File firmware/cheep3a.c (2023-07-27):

/*
 * Cheep3a firmware
 * 07-25-2023 E. Brombaugh
 */

#include "ch32v003fun.h"
#include <stdio.h>
#include <string.h>

// Systick IRQ
#include "systick.h"

// EEPROM emulation for mode storage
#include "eeprom.h"

// LED driver
#include "led.h"

// Sync input driver
#include "sync.h"

// prototype for the DAC update function used in the driver
// must come prior to the driver include
void dac_update(uint16_t *buffer);

// the SPI DAC driver
#include "spi_dac.h"

// ADC driver
#include "adc.h"

// Expo
#include "expo.h"

// Noise
#include "noise.h"

// this table contains a 512-sample 16-bit sine waveform
#include "Sine16bit.h"

/* audio state */
uint8_t mode, psync;
int32_t osc_phs[2], osc_frq[2];
int16_t clk_nz[2];
int64_t fm_phs;
uint16_t fm_index, fm_ratio, live_fm_ratio;

/*
 * hysteresis & reduction
 */
void ratio_hyst(uint16_t *old, uint16_t in, uint8_t shift)
{
	int16_t diff, guard = (1<<(shift-2));
	
	/* Special case - don't guardband at endpoints */
	if((in == 0) || (in == 0x3FF))
	{
		*old = in >> shift;
		return;
	}
	
	/* find abs val of diff */
	diff = (int16_t)(*old << shift) - (int16_t)in;
	if(diff<0)
		diff = -diff;
	
	/* exceeds guardband ? */
	if(diff > guard)
	{
		/* yes so update prev */
		*old  = in >> shift;
	}
}

/*
 * 32-bit phase to 16-bit sine with quarter-cycle LUT
 */
#define SINE_LUT_MASK ((1<<SINE_LUT_BITS)-1)
int16_t SineWave(uint32_t Phs)
{
	int16_t result;
	int16_t sgn = (Phs & 0x80000000) ? 1 : 0;
	uint32_t dir = (Phs & 0x40000000) ? SINE_LUT_MASK : 0;
	
	Phs = ((Phs>>(30-SINE_LUT_BITS)) & SINE_LUT_MASK) ^ dir;
	result = Sine16bit[Phs];
	
	/* sign inversion w/o multiply */
	return sgn ? ~result + 1 : result ;
}

/*
 * DAC buffer updates - called at IRQ time
 */
void dac_update(uint16_t *buffer)
{
	uint8_t i;
	int16_t phs, amp, pw1, pw2;
	int32_t tphs, tmp_phs;
	
	// Get sync input
	if(sync_re())
	{
		osc_phs[0] = osc_phs[1] = 0;
	}
	
	// fill the buffer with stereo data
	switch(mode)
	{
		/* sine oscillators with separate pitch */
		case 1:	// Normal range
		case 2:	// LFO range
			osc_frq[0] = expo_calc(1023-adc_buffer[0], mode & 1 ? 0 : 5);
			osc_frq[1] = expo_calc(1023-adc_buffer[1], mode & 1 ? 0 : 5);
			amp = 511 - adc_buffer[2];
			for(i=0;i<DACBUFSZ/2;i+=2)
			{
				// right chl
				*buffer++ = (amp * SineWave(osc_phs[0]))>>9;
				osc_phs[0] += osc_frq[0];
				
				// left chl
				*buffer++ = (amp * SineWave(osc_phs[1]))>>9;
				osc_phs[1] += osc_frq[1];
			}
			break;
		
		/* sine oscillator with two outputs, phase / amp control */
		case 3:	// Normal range
			osc_frq[0] = expo_calc(1023-adc_buffer[0], 0);
			phs = (1023 - adc_buffer[1])>>2;
			amp = 511 - adc_buffer[2];
			for(i=0;i<DACBUFSZ/2;i+=2)
			{
				// right chl
				*buffer++ = (amp * SineWave(osc_phs[0]))>>9;
				
				// left chl
				*buffer++ = (amp * SineWave(osc_phs[0] + (phs<<22)))>>9;
				
				osc_phs[0] += osc_frq[0];
			}
			break;
		
		/* square oscillator with two outputs, PWM control */
		case 4:
			osc_frq[0] = expo_calc(1023-adc_buffer[0], 0);
			pw1 = (511 - adc_buffer[1]);
			pw1 = pw1 > 480 ? 480 : pw1;
			pw1 = pw1 < -480 ? -480 : pw1;
			pw2 = (511 - adc_buffer[2]);
			pw2 = pw2 > 480 ? 480 : pw2;
			pw2 = pw2 < -480 ? -480 : pw2;
			for(i=0;i<DACBUFSZ/2;i+=2)
			{
				// right chl
				*buffer++ = (osc_phs[0]>>22) > pw1 ? -32767 : 32767;
				
				// left chl
				*buffer++ = (osc_phs[0]>>22) > pw2 ? -32767 : 32767;
				
				osc_phs[0] += osc_frq[0];
			}
			break;

		/* 2-op FM */
		case 5:
			osc_frq[0] = expo_calc(1023-adc_buffer[0], 0);
			fm_index = (1023 - adc_buffer[1])<<2;
			ratio_hyst(&fm_ratio, (1023 - adc_buffer[2]), 4);
			for(i=0;i<DACBUFSZ/2;i+=2)
			{
				/* compute FM */
				tmp_phs = fm_phs >> 3;
				if((tmp_phs & 0xFF000000)==0)
					live_fm_ratio = fm_ratio;	// to avoid ratio change glitches
				tmp_phs = (tmp_phs * live_fm_ratio);
				int16_t mod = SineWave(tmp_phs);
				tmp_phs = (mod * fm_index)<<4;
				tmp_phs = tmp_phs + fm_phs;
				
				/* send to DAC */
				*buffer++ = mod;
				*buffer++ = SineWave(tmp_phs);
				
				/* update phase */
				fm_phs += osc_frq[0];
			}
			break;
		
		/* clocked noise with two separate oscs */
		case 6:
			osc_frq[0] = expo_calc(1023-adc_buffer[0], 0);
			osc_frq[1] = expo_calc(1023-adc_buffer[1], 0);
			for(i=0;i<DACBUFSZ/2;i+=2)
			{
				uint16_t wht = wht_noise();
				
				// right chl
				tphs = osc_phs[0];
				osc_phs[0] += osc_frq[0];
				if(((tphs & 0x80000000) == 0x80000000) &&
					((osc_phs[0] & 0x80000000) == 0x00000000))
					clk_nz[0] = wht;
				*buffer++ = clk_nz[0];
				
				// left chl
				tphs = osc_phs[1];
				osc_phs[1] += osc_frq[1];
				if(((tphs & 0x80000000) == 0x80000000) &&
					((osc_phs[1] & 0x80000000) == 0x00000000))
					clk_nz[1] = wht;
				*buffer++ = clk_nz[1];
			}
			break;
		
		/* white and pink noise */
		case 7:
			for(i=0;i<DACBUFSZ/2;i+=2)
			{
				uint16_t wht = wht_noise();
				
				// right chl
				*buffer++ = (int16_t)wht;
				
				// left chl
				*buffer++ = pnk_noise(wht);
			}
			break;
		
		/* do nothing */
		default:
			memset(buffer, 0, DACBUFSZ * sizeof(int16_t));
			break;
	}
}

/* build version in simple format */
const char *fwVersionStr = "V1.0";

/* build time */
const char *bdate = __DATE__;
const char *btime = __TIME__;

/*
 * Start here
 */
int main()
{
	uint8_t eepend = 0;
	uint32_t eegoal;
	
	// init audio state
	mode = 0;
	fm_phs = 0;
	osc_phs[0] = 0;
	osc_phs[1] = 0;
	osc_frq[0] = 0x01000000;
	osc_frq[1] = 0x00400000;
	init_noise();
	
	// setup basic stuff - clocks, serial, etc
	SystemInit();

	// start serial @ default 115200bps
	Delay_Ms( 100 );
	printf("\r\r\n\nCheep3a\n\r");
	printf("Version: %s\n\r", fwVersionStr);
	printf("Build Date: %s\n\r", bdate);
	printf("Build Time: %s\n\r", btime);

	// init systick @ 1ms rate
	printf("initializing systick...");
	systick_init();
	printf("done.\n\r");
	
	// init LED
	printf("initializing LED...");
	init_led();
	printf("done.\n\r");
	
	// init sync
	printf("initializing sync...");
	sync_init();
	printf("done.\n\r");
	
	// init SPI DAC
	printf("initializing spi dac...");
	spidac_init();
	printf("done.\n\r");
		
	// init ADC
	printf("initializing adc...");
	adc_init();
	printf("done.\n\r");
	
	/* load the operation mode */
	mode = eeprom_read();
	if(mode>7)
	{
		mode = 1;
		eepend = 1;
		eegoal = SysTick_goal(5000);
		printf("Default mode used\n");
	}
	set_led(mode);
	printf("initialized mode to %d\n\r", mode);
	
	printf("looping...\n\r");
	while(1)
	{
		/* check for button press */
		if(SysTick_get_button())
		{
			mode++;
			mode = mode > 7 ? 1 : mode;
			printf("Mode %d\n\r", mode);
			eepend = 1;
			eegoal = SysTick_goal(5000);
			set_led(mode);
		}
		
		/* check if it's time to save the mode */
		if(eepend && !SysTick_check(eegoal))
		{
			eeprom_write(mode);
			eepend = 0;
			printf("Saved mode %d\n\r", mode);
		}
	}
}

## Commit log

2023-07-25 Initial checkin
    [cheep3a.kicad_pcb, cheep3a.kicad_sch, cheep3a_JLCPCB_BOM.csv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]
2023-07-27 Improved sine phase resolution 16x, added 2-op FM mode, clean up PWM ends.

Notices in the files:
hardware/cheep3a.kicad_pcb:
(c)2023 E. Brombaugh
